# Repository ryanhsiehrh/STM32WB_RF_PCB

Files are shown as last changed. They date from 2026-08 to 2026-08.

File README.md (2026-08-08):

# STM32WB_RF_PCB
Custom 4-layer developement board centered around the STM32WB55CEU6 MCU. The board includes 2.4GHz BLE RF cicuitry, ESD protected USB, SWD, and communication interfaces: UART, I2C, SPI, GPIO.

---

# Components

* **Microcontroller**: STM32WB55CEU6 
* **Power Supply**: USB Type-C stepped down through a 3.3V LDO regulator.
* **Clock:** Dual high-speed external (32 MHz) and low-speed external (32.768 kHz) crystal oscillators.
* **Wireless & RF:** 2.4 GHz RF featuring an impedance-matched filter network and $50\Omega$ trace feeding a U.FL antenna connector.
* **USB & Protection:** USB Type-C interface with a USBLC6-2SC6 ESD protection IC on $90\Omega$ differential data pairs.
* **Peripherals & Interfaces:** General-Purpose I/O (I/O and Analog), I2C, SPI, and UART headers
* **Debug & User Controls:** Tag-Connect SWD programming header, BOOT0 switch, and user status LED.
* **PCB Stackup:** GND planes on layers 1-3, 3V3 plane on layer 4, and contains via stiching to limit interference between planes.

---

**Schematic:**

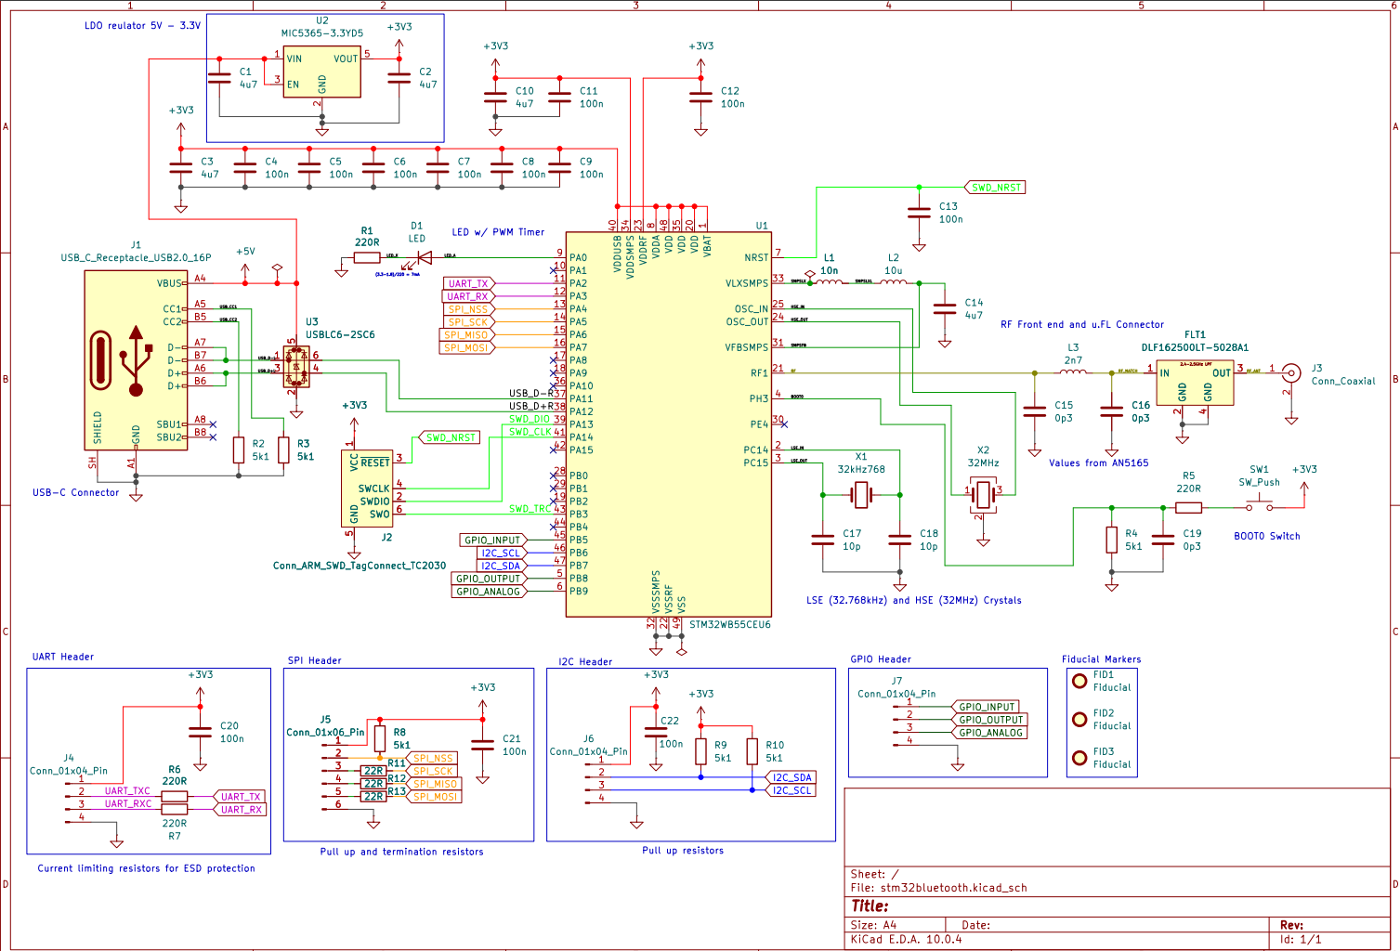
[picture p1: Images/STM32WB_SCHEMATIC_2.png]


**PCB:**

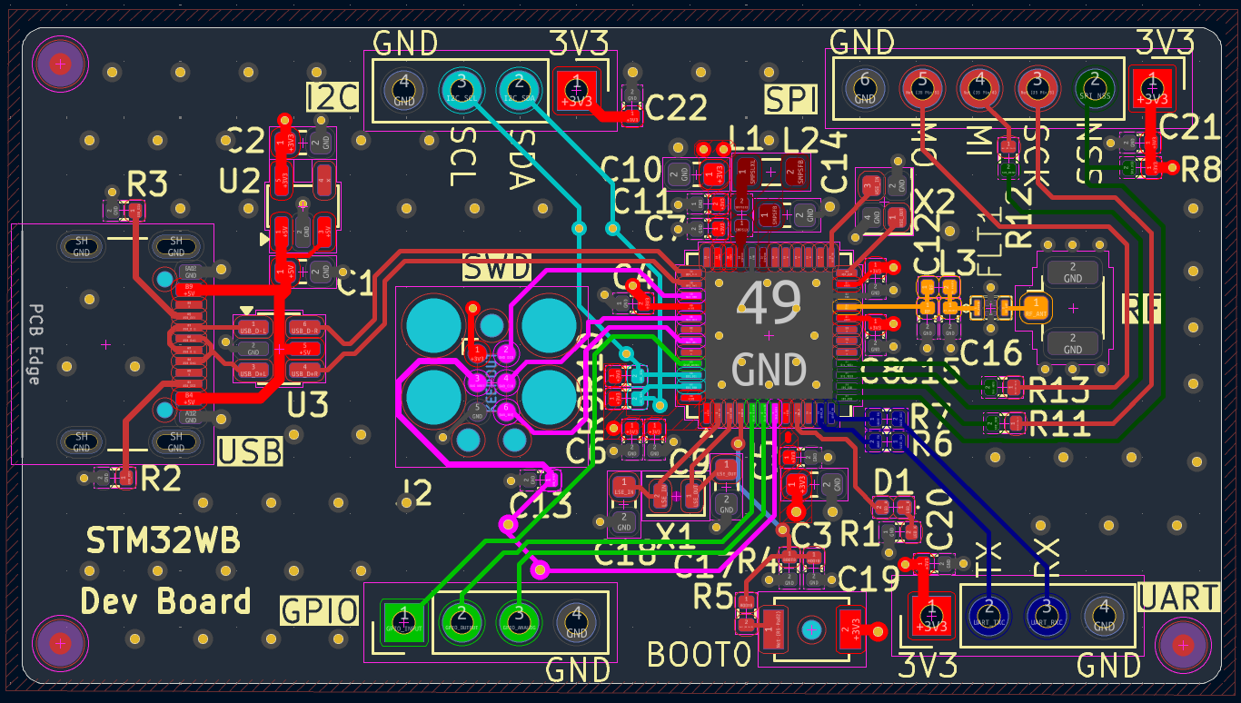
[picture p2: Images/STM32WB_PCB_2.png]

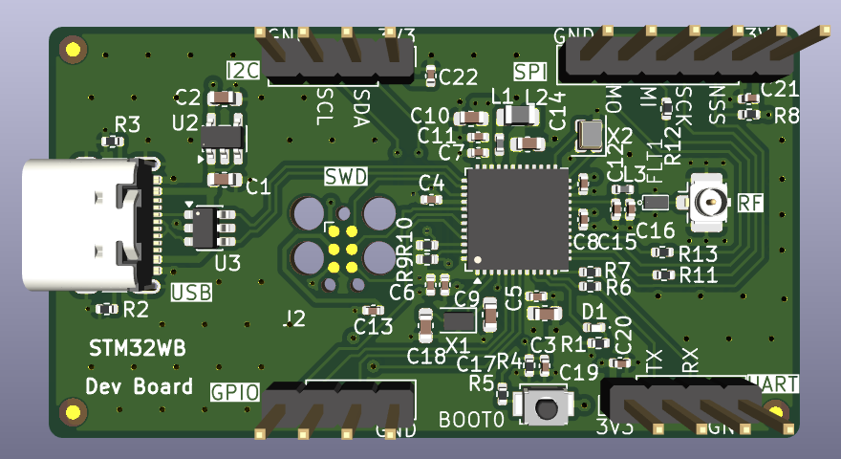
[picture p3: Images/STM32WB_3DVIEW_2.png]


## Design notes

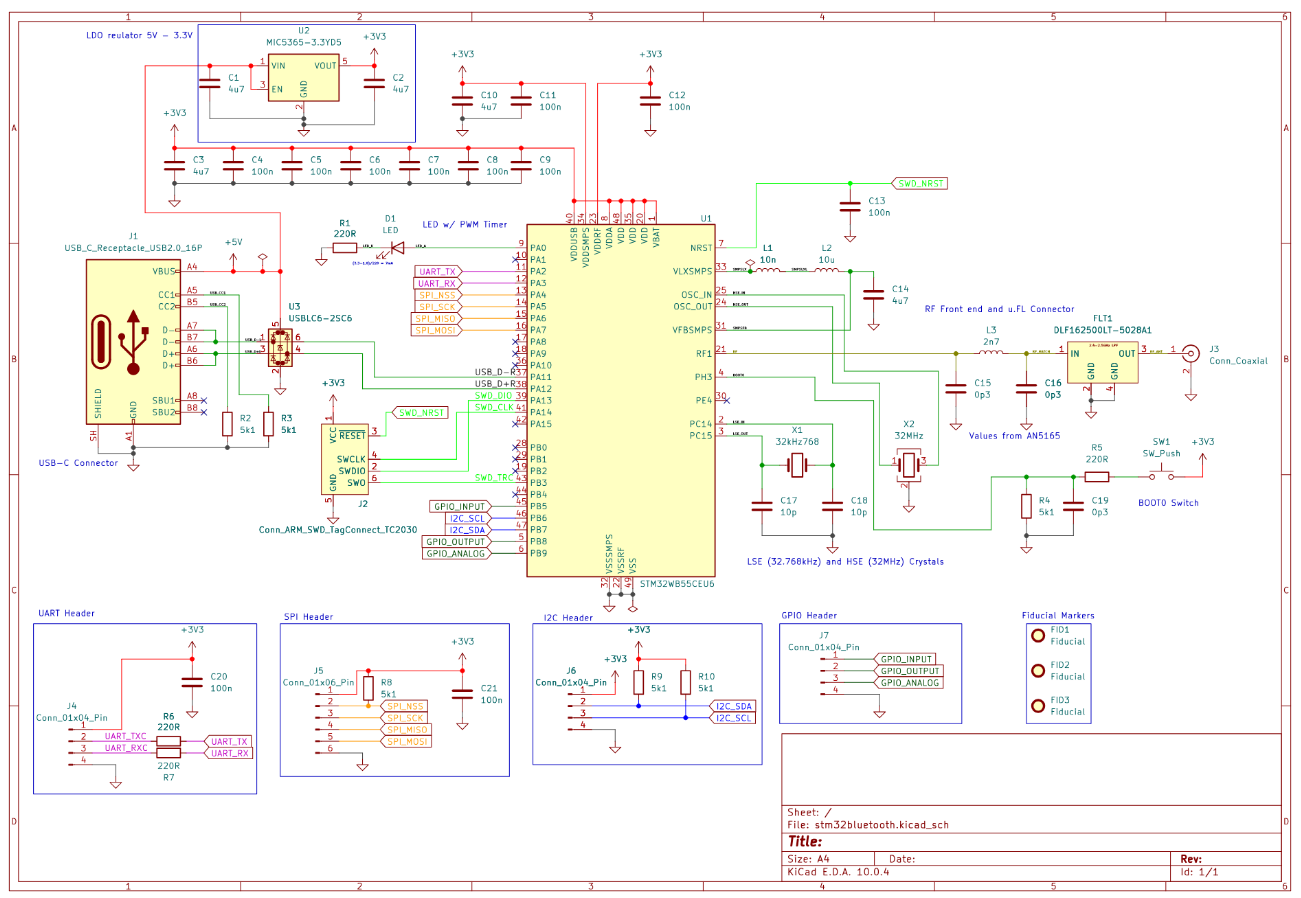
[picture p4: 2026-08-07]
Images/STM32WB_SCHEMATIC.png

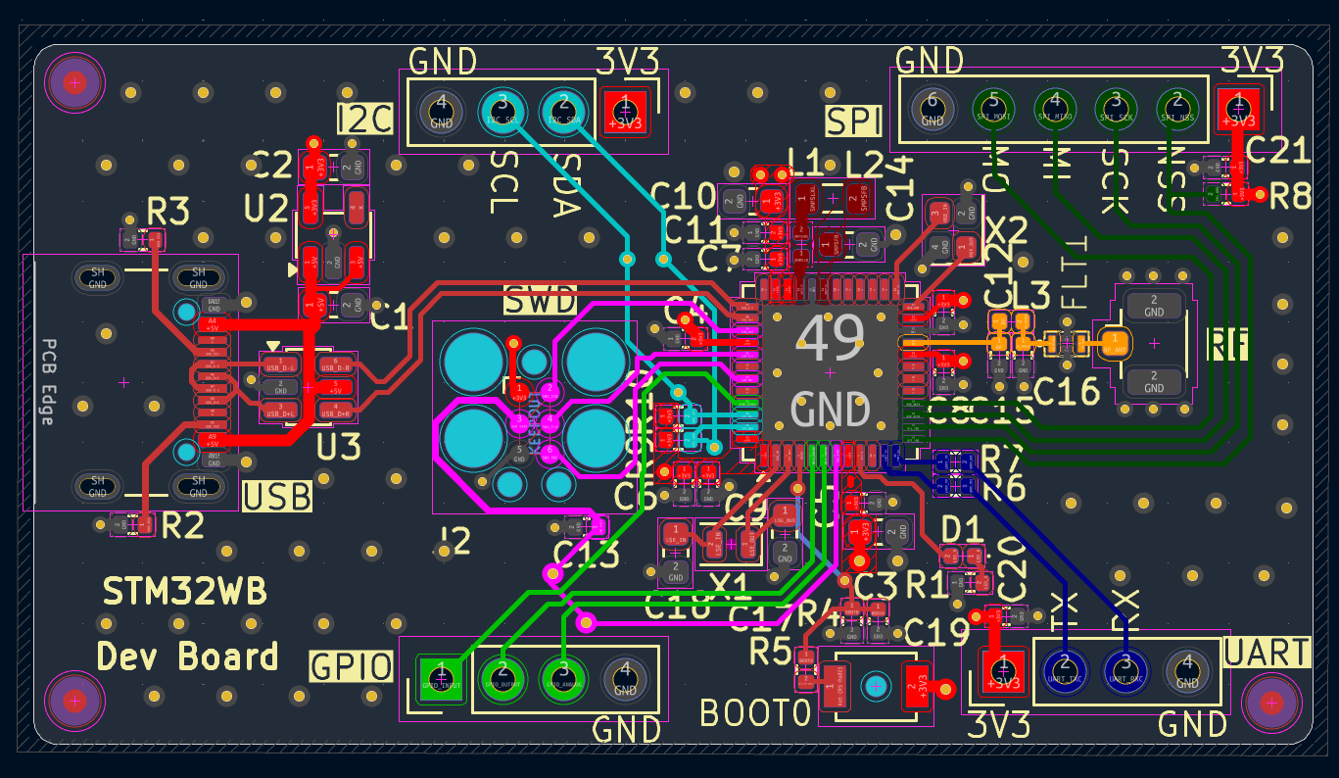
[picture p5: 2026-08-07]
Images/STM32WB_PCB.png

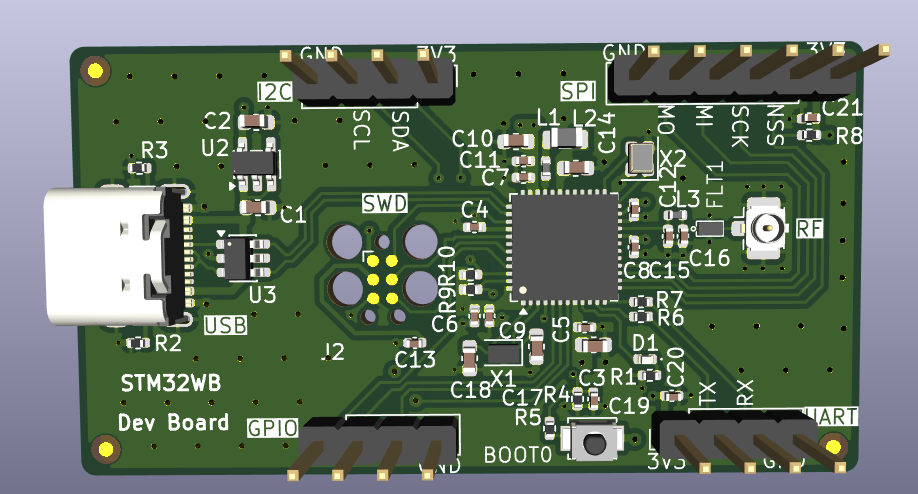
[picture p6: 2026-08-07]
Images/STM32WB_3DVIEW.png

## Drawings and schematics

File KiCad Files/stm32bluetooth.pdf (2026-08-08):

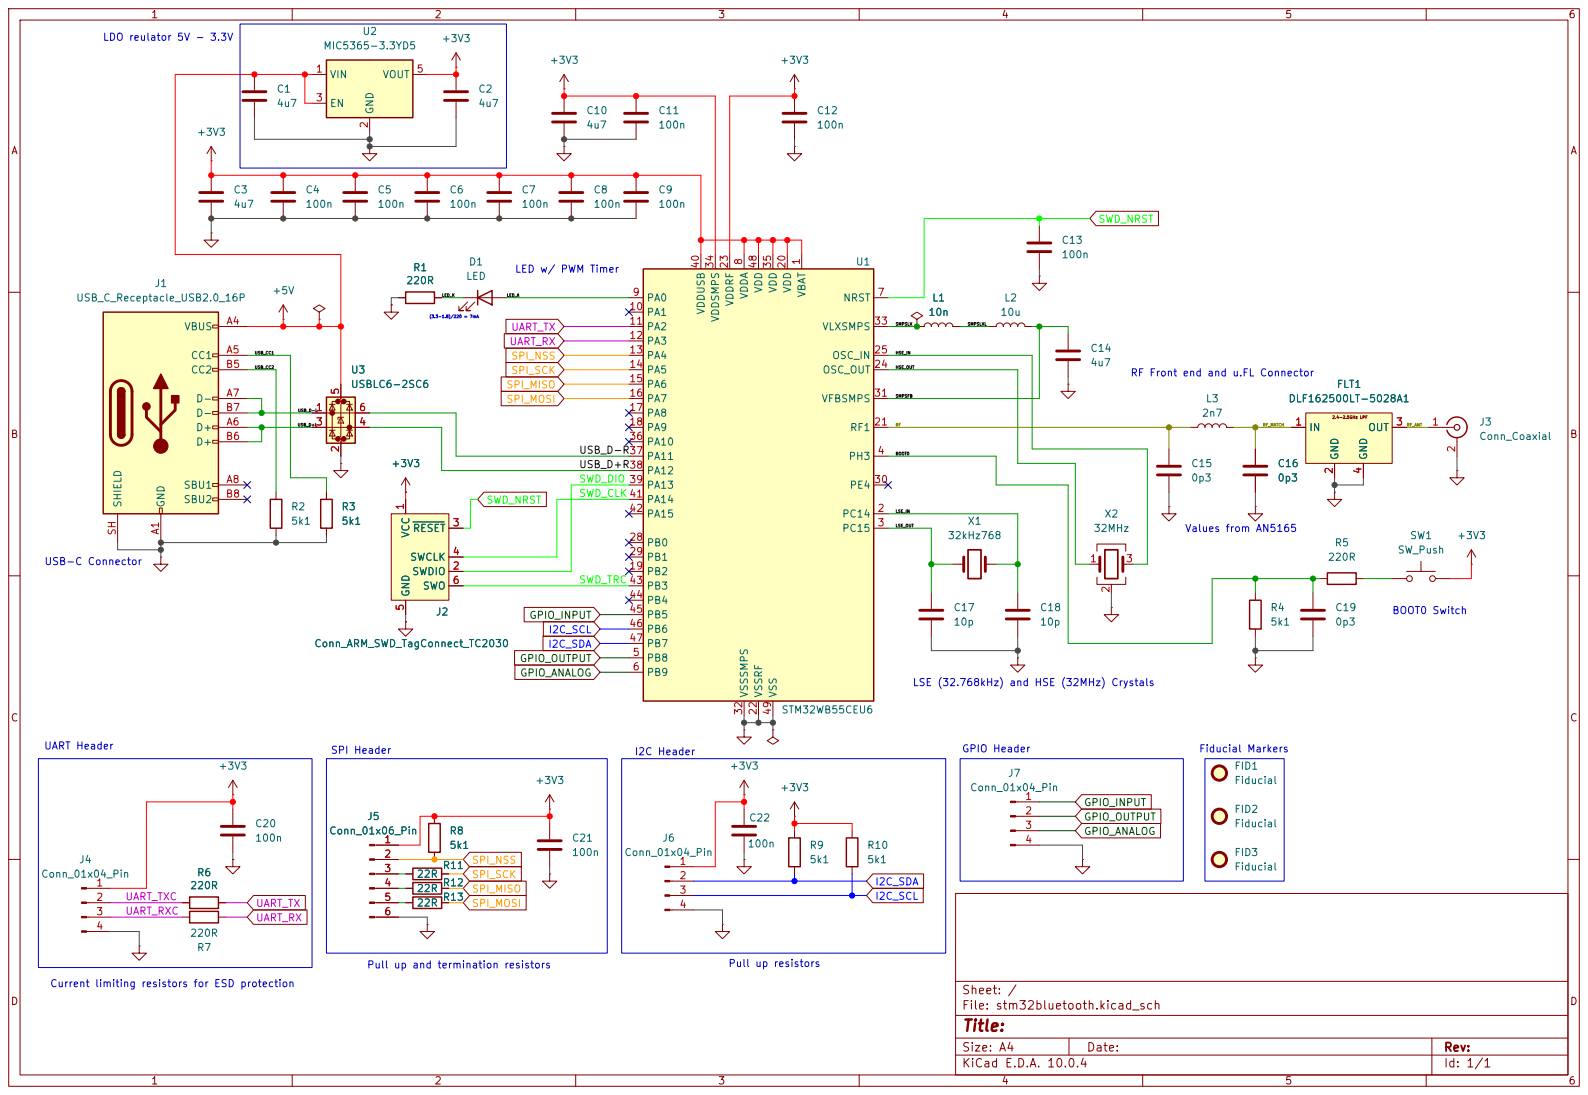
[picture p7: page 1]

RF Front end and u.FL Connector Pull up and termination resistors

Size: A4 | Rev:
KiCad E.D.A. 10.0.4 | Id: 1/1

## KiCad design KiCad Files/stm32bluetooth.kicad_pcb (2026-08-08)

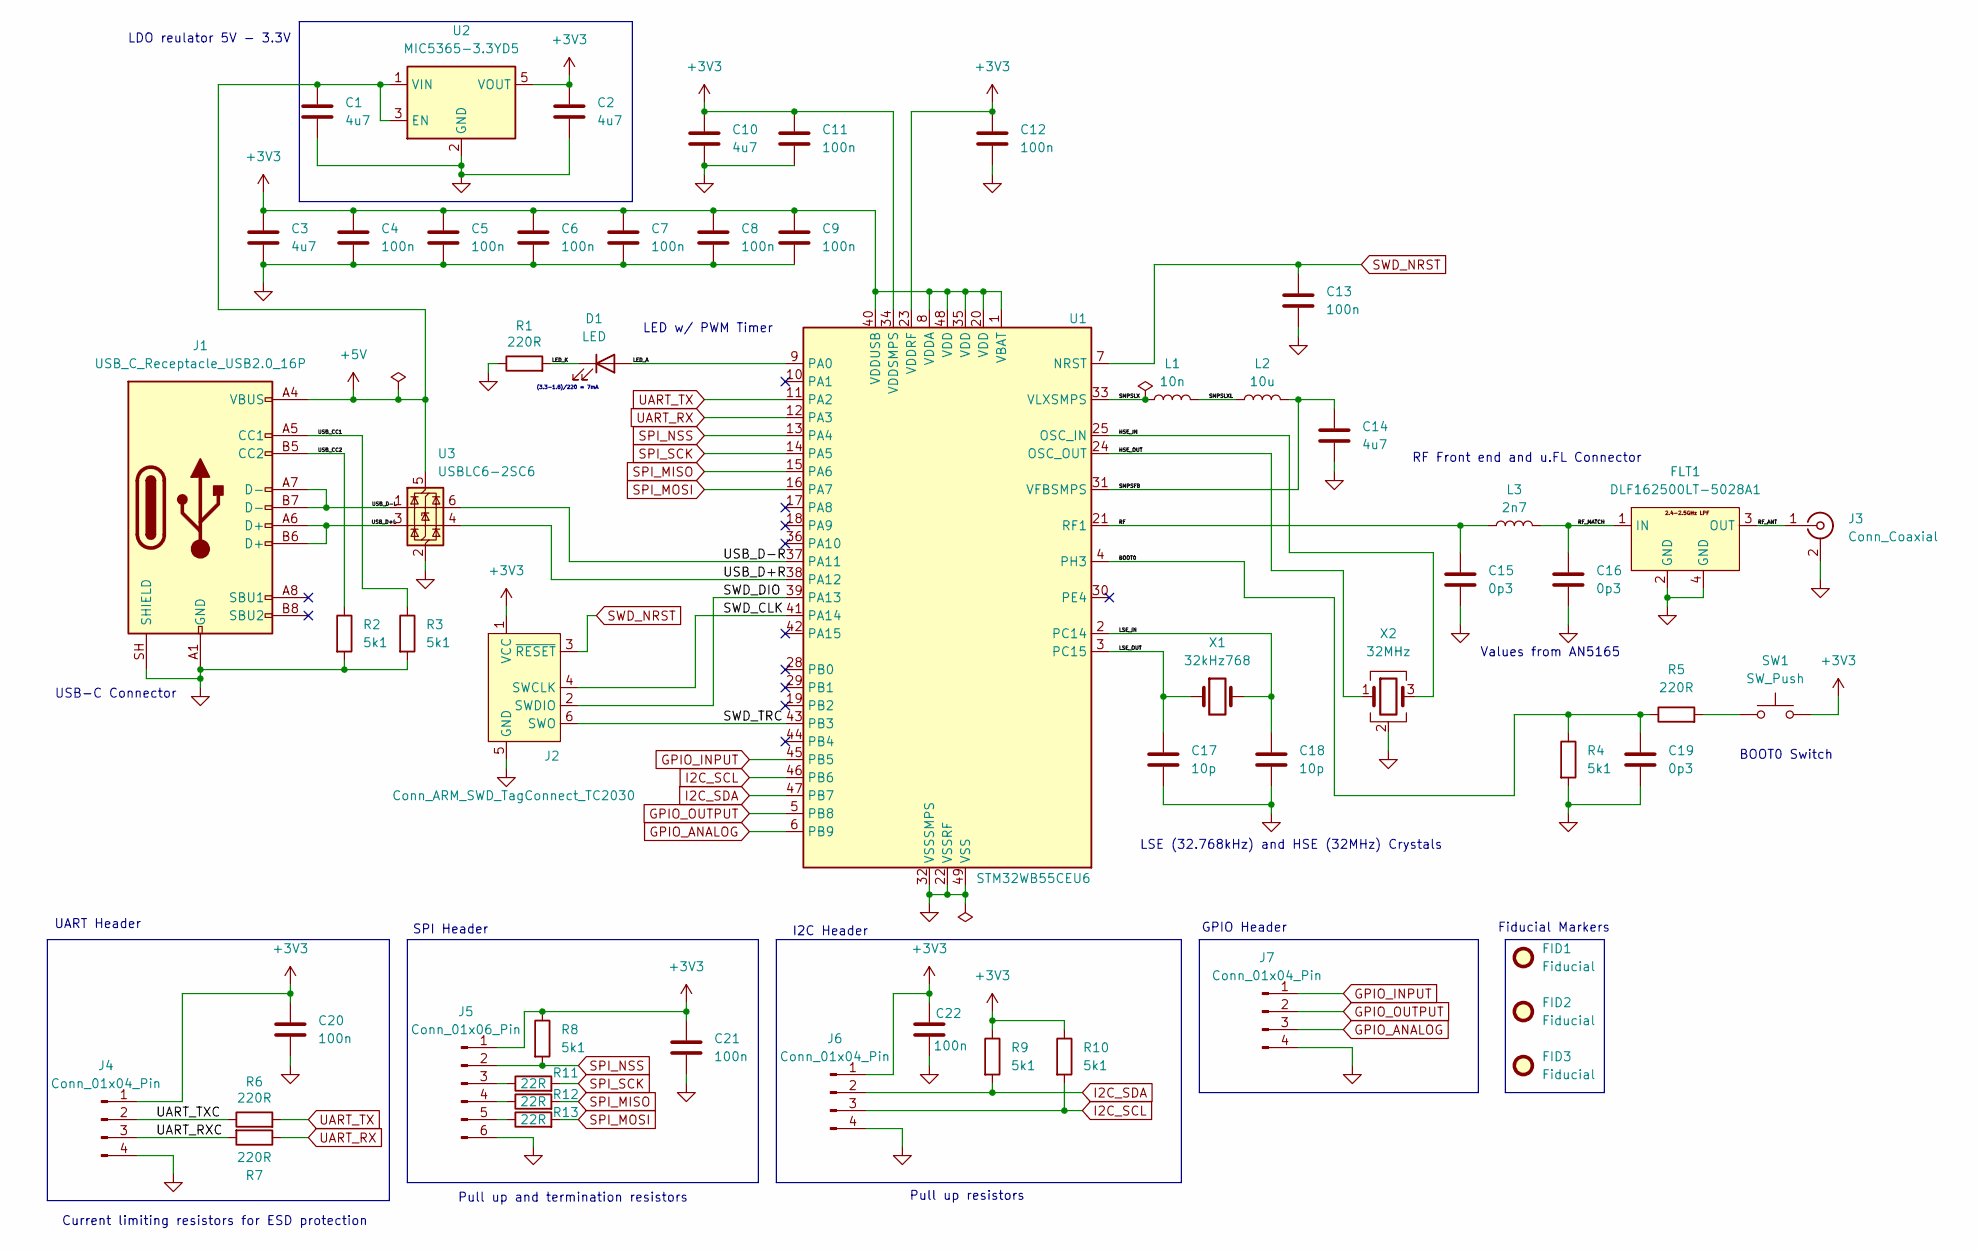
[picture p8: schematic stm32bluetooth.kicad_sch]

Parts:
C1, C2, C3, C10, C14: 4u7; C_0603_1608Metric
C4, C5, C6, C7, C8, C9, C11, C12, C13, C20, C21, C22: 100n; C_0402_1005Metric
C15, C16, C19: 0p3; C_0402_1005Metric
C17, C18: 10p; C_0603_1608Metric
D1: LED; LED_0402_1005Metric
FID1, FID2, FID3: Fiducial; Fiducial_1mm_Mask2mm
FLT1: DLF162500LT-5028A1
J1: USB_C_Receptacle_USB2.0_16P; USB_C_Receptacle_GCT_USB4105-xx-A_16P_TopMnt_Horizontal
J2: Conn_ARM_SWD_TagConnect_TC2030; Tag-Connect_TC2030-IDC-FP_2x03_P1.27mm_Vertical
J3: Conn_Coaxial; U.FL_Hirose_U.FL-R-SMT-1_Vertical
J4, J6, J7: Conn_01x04_Pin; PinHeader_1x04_P2.54mm_Vertical
J5: Conn_01x06_Pin; PinHeader_1x06_P2.54mm_Vertical
L1: 10n; L_0402_1005Metric
L2: 10u; L_0805_2012Metric
L3: 2n7; L_0402_1005Metric
R1, R5, R6, R7: 220R; R_0402_1005Metric
R2, R3, R4, R8, R9, R10: 5k1; R_0402_1005Metric
R11, R12, R13: 22R; R_0402_1005Metric
SW1: SW_Push; SW_SPST_B3U-1000P-B
U1: STM32WB55CEU6; QFN-48-1EP_7x7mm_P0.5mm_EP5.6x5.6mm
U2: MIC5365-3.3YD5; TSOT-23-5
U3: USBLC6-2SC6; SOT-23-6
X1: 32kHz768; Crystal_SMD_2012-2Pin_2.0x1.2mm
X2: 32MHz; Crystal_SMD_2016-4Pin_2.0x1.6mm

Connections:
+3V3: C2.1, C3.1, C4.2, C5.1, C6.1, C7.1, C8.1, C9.1, C10.1, C11.2, C12.1, C20.1, C21.1, C22.1, J2.1 (VCC), J4.1, J5.1, J6.1, R8.1, R9.1, R10.1, SW1.2, U1.1 (VBAT), U1.8 (VDDA), U1.20 (VDD), U1.23 (VDDRF), U1.34 (VDDSMPS), U1.35 (VDD), U1.40 (VDDUSB), U1.48 (VDD), U2.5 (VOUT)
+5V: C1.1, J1.A4 (VBUS), J1.A9 (VBUS), J1.B4 (VBUS), J1.B9 (VBUS), U2.1 (VIN), U2.3 (EN), U3.5 (VBUS)
/BOOT0: C19.1, R4.1, R5.1, U1.4 (PH3)
/HSE_IN: U1.25 (OSC_IN), X2.3
/HSE_OUT: U1.24 (OSC_OUT), X2.1
/LED_A: D1.2 (A), U1.9 (PA0)
/LED_K: D1.1 (K), R1.2
/LSE_IN: C18.1, U1.2 (PC14), X1.2
/LSE_OUT: C17.1, U1.3 (PC15), X1.1
/RF: C15.1, L3.1, U1.21 (RF1)
/RF_ANT: FLT1.3 (OUT), J3.1 (In)
/RF_MATCH: C16.1, FLT1.1 (IN), L3.2
/SMPSFB: C14.1, L2.2, U1.31 (VFBSMPS)
/SMPSLX: L1.1, U1.33 (VLXSMPS)
/SMPSLXL: L1.2, L2.1
/SWD_CLK: J2.4 (SWCLK), U1.41 (PA14)
/SWD_DIO: J2.2 (SWDIO), U1.39 (PA13)
/SWD_TRC: J2.6 (SWO), U1.43 (PB3)
/UART_RXC: J4.3, R7.2
/UART_TXC: J4.2, R6.1
/USB_CC1: J1.A5 (CC1), R3.1
/USB_CC2: J1.B5 (CC2), R2.1
/USB_D+L: J1.A6 (D+), J1.B6 (D+), U3.3 (I/O2)
/USB_D+R: U1.38 (PA12), U3.4 (I/O2)
/USB_D-L: J1.A7 (D-), J1.B7 (D-), U3.1 (I/O1)
/USB_D-R: U1.37 (PA11), U3.6 (I/O1)
GND: C1.2, C2.2, C3.2, C4.1, C5.2, C6.2, C7.2, C8.2, C9.2, C10.2, C11.1, C12.2, C13.2, C14.2, C15.2, C16.2, C17.2, C18.2, C19.2, C20.2, C21.2, C22.2, FLT1.2 (GND), FLT1.4 (GND), J1.A1 (GND), J1.A12 (GND), J1.B1 (GND), J1.B12 (GND), J1.SH (SHIELD), J2.5 (GND), J3.2 (Ext), J4.4, J5.6, J6.4, J7.4, R1.1, R2.2, R3.2, R4.2, U1.22 (VSSRF), U1.32 (VSSSMPS), U1.49 (VSS), U2.2 (GND), U3.2 (GND), X2.2 (G), X2.4 (G)
GPIO_ANALOG: J7.3, U1.6 (PB9)
GPIO_INPUT: J7.1, U1.45 (PB5)
GPIO_OUTPUT: J7.2, U1.5 (PB8)
I2C_SCL: J6.3, R10.2, U1.46 (PB6)
I2C_SDA: J6.2, R9.2, U1.47 (PB7)
unnamed: J5.3, R11.1
unnamed: J5.4, R12.1
unnamed: J5.5, R13.1
unnamed: R5.2, SW1.1
SPI_MISO: R12.2, U1.15 (PA6)
SPI_MOSI: R13.2, U1.16 (PA7)
SPI_NSS: J5.2, R8.2, U1.13 (PA4)
SPI_SCK: R11.2, U1.14 (PA5)
SWD_NRST: C13.1, J2.3 (~RESET), U1.7 (NRST)
UART_RX: R7.1, U1.12 (PA3)
UART_TX: R6.2, U1.11 (PA2)

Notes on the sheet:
RF Front end and u.FL Connector
Current limiting resistors for ESD protection
Pull up resistors
LDO reulator 5V - 3.3V
USB-C Connector
GPIO Header
(3.3-1.8)/220 = 7mA
Fiducial Markers
Values from AN5165
SPI Header
LSE (32.768kHz) and HSE (32MHz) Crystals
UART Header
Pull up and termination resistors
I2C Header
LED w/ PWM Timer
BOOT0 Switch

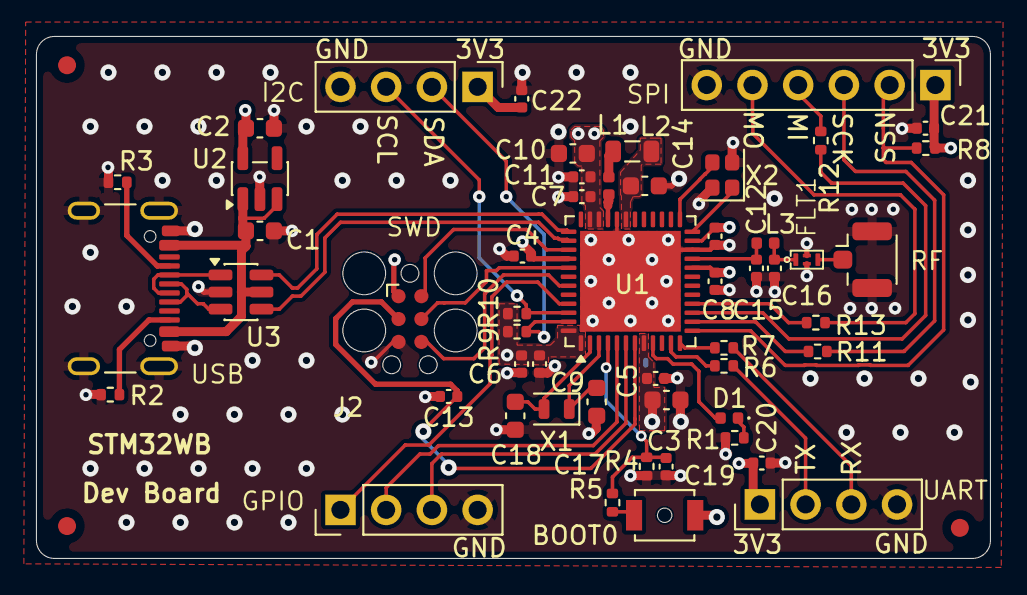
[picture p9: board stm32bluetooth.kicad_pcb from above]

Board: 4 copper layers, 53.0 x 29.0 mm, 56 parts (0 on the bottom side), 43 nets.
